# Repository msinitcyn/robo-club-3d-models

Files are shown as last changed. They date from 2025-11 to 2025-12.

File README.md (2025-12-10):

# 3D Models for Robotics Club



## Project: Robot Maze

### System Description

Building a maze for teaching robot navigation. The system consists of:

**Base:**
- Holes diameter: 5mm
- Grid spacing: 12.5mm
- Mounting points for wall connectors

**Walls:**
- Material: plywood (9mm) or cardboard (2mm)
- Shape: rectangles cut to size
- Insert into connector grooves
- For cardboard use models with `_flexible` suffix

**3D-printed connectors:**
- Height: 10mm
- Wall thickness: 2mm
- Groove width: 9mm (for plywood)
- Reach to mounting hole: 56.5mm (4.5 grid steps)

### Connector Types

1. **end_cap** - end cap (1 exit)
2. **straight_joint** - straight connector (2 opposite exits)
3. **corner_joint** - corner (2 exits at 90°)
4. **t_joint** - T-shaped (3 exits)
5. **cross_joint** - cross (4 exits)

Each type available in 4 variants:
- Base (no dowels, for plywood)
- `_dowel` (with dowels for base mounting)
- `_flexible` (flexible walls for cardboard, no dowels)
- `_dowel_flexible` (flexible walls + dowels)

**Total: 20 models**

### Project Structure

```
maze/
  scad/           # OpenSCAD source files
    common.scad   # Common modules and functions
    *_joint*.scad # Different connector types
  stl/            # Locally built STL (in .gitignore)
artifacts/        # CI/CD artifacts (automatic)
  current/        # Latest build from main branch
  v1.0/           # Version builds (for tags)
.github/
  workflows/      # GitHub Actions for auto-build
```

### Getting Ready STL Files

**Option 1: Download from GitHub (recommended)**
- Latest version: `artifacts/current/` in repository
- Stable version: [Releases](../../releases) → download attached STL files

**Option 2: Build locally**
```bash
./export_all_stl.sh
```
STL files will appear in `maze/stl/`

### Usage

1. Download STL files from `artifacts/current/` or [Releases](../../releases)
2. Print needed connectors
3. Prepare walls from plywood (9mm) or cardboard (2mm)
4. Assemble maze by inserting walls into connector grooves

### Development

1. Edit models: `maze/scad/*.scad` files in OpenSCAD
2. Test locally: `./export_all_stl.sh`
3. Commit changes → GitHub Actions automatically builds STL
4. For release: create tag `git tag v1.1 && git push origin v1.1`

### Parameters for Modification

In `common.scad` you can configure:

**Main dimensions:**
- `CENTER_SIZE = 9` - center square size
- `SLEEVE_REACH = 56.5` - distance to mounting hole
- `GROOVE_WIDTH = 9` - groove width (for plywood)
- `WALL_HEIGHT = 10` - wall height
- `WALL_THICKNESS = 2` - wall thickness
- `BASE_THICKNESS = 2` - base thickness

**Dowels:**
- `DOWEL_DIAMETER = 4.5` - dowel diameter
- `DOWEL_DEPTH = 3` - dowel depth

**Flexible walls (for cardboard):**
- `CARDBOARD_THICKNESS = 2` - cardboard thickness
- `FLEXIBLE_WALL_HEIGHT = 20` - flexible wall height (2x higher)
- `CURVE_POWER = 2` - curve power (2 = parabola)
- `TILT_ANGLE_EXTRA = 5` - additional tilt angle

### CI/CD Pipeline

On push to GitHub, STL build is triggered automatically:

**For regular commits (main branch):**
- All STL files are built
- Committed to `artifacts/current/`
- Available as GitHub Artifacts (90 days)

**For version tags (v1.0, v1.1, etc.):**
- All STL files are built
- GitHub Release is created with attached STL
- Available as GitHub Artifacts with version name

This allows to always have print-ready files without need for local OpenSCAD installation.

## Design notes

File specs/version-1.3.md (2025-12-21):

# Version 1.3 - LEGO Compatibility Improvements

Improvements to make parts better compatible with standard LEGO dimensions

## Changes Checklist

- [x] **1. Adjust LEGO base dimensions to match standard LEGO parts**
  - Files: All `lego_base_*.scad` files (including `_double` variants)
  - Changes in `maze/scad/lego.scad`:
    - Add new constants for LEGO-compatible dimensions
    - `LEGO_BASE_WIDTH` - width for single row of studs (≈8mm, to be tuned)
    - `LEGO_SLEEVE_LENGTH` - calculated to have exactly 7 studs total (center + sleeve) with equal margins from edges
    - Update modules to use new dimensions
  - Reason: Current parts too wide to attach to multi-row LEGO bricks

- [ ] **2. Create prototype with reduced base width**
  - File: `maze/scad/cross_joint_dowel_8_5_base_width.scad`
  - Change: `CENTER_SIZE = 8.5` (instead of 9.0)
  - Version tag: `v1.3.2-base.8.5.mm.proto`
  - Reason: Test if 8.5mm base fits better into 12.5mm grid holes (currently loose fit)
  - Note: Temporary experimental part - if successful, apply to all parts; if too tight, delete

## Implementation Notes

### For Change 1:
- Center should have 1 stud
- Each sleeve should have 3 studs
- Total: 1 + 3 + 3 = 7 studs
- Edge margins should be equal on both sides
- Formula: `LEGO_SLEEVE_LENGTH = 3 * LEGO_UNIT + margins`

### For Change 2:
- Single file to test reduced base size
- If approved, will become standard in future version
- If rejected, will be deleted

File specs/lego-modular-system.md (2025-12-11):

# Specification: LEGO-Compatible Modular System

## Concept

The system splits models into two layers connected via LEGO-compatible interface:

1. **Bottom Layer (Base)**
   - Optional dowels for mounting to grid base
   - LEGO studs on top for connecting upper layer

2. **Upper Layer (Wall Sleeve)**
   - LEGO holes underneath for connecting to base
   - Grooves on top for inserting plywood/cardboard walls

## Advantages

- **Modularity**: Print only the sleeves you need, attach to any base configuration
- **Flexibility**: Rigid walls (9mm plywood) or flexible walls (2mm cardboard)
- **Compatibility**: Can use real LEGO bricks for walls
- **Efficiency**: Empty center is normal - print 4 sleeves + 1 cross base for any configuration

## LEGO Standards

- Stud diameter: **4.8mm**
- Stud height: **1.8mm**
- Unit spacing: **8mm** (1 LEGO unit)
- Hole diameter: **5.0mm** (with clearance)
- Tube outer diameter: **6.5mm** (for spring grip)
- Tube inner diameter: **5.0mm**

## Dimensions

### Current Parameters
- `CENTER_SIZE = 9mm` (center square)
- `SLEEVE_LENGTH = 55mm` (actual sleeve length)
- `SLEEVE_REACH = 59.5mm` (calculated: from center to mounting hole)

### Stud Positions

**Formula:**
```
first_stud = LEGO_UNIT - (CENTER_SIZE/2 % LEGO_UNIT) = 8 - 4.5 = 3.5mm
```

**Center part:**
- 1 stud at center: **(0, 0)**

**Sleeve (local coordinates):**
- Sleeve starts at global coordinate **4.5mm** (edge of center square)
- Studs at local positions: **3.5, 11.5, 19.5, 27.5, 35.5, 43.5mm**

**Global coordinates (after assembly):**
- Center: **0mm**
- Sleeve: **8, 16, 24, 32, 40, 48mm**

**Verification:** All positions are multiples of 8mm ✓

### Visualization (top view, one sleeve along X axis)

```
    Center (9×9mm)    |      Sleeve (55mm)
                      |
    ----[═]----       |   [═]  [═]  [═]  [═]  [═]  [═]
        0mm           |   8   16   24   32   40   48
                    4.5mm (sleeve start)
```

## Module Structure

### Bottom Layer (Bases)
**File prefix:** `lego_base_*`

- `lego_base_straight[_dowel].scad` - straight base (center + 2 opposite sleeves)
- `lego_base_corner[_dowel].scad` - corner base (center + 2 sleeves at 90°)
- `lego_base_t[_dowel].scad` - T-shaped base (center + 3 sleeves)
- `lego_base_cross[_dowel].scad` - cross base (center + 4 sleeves)

**Variants:**
- Base (no dowels)
- `_dowel` (with dowels for grid mounting)

**Total:** 8 models

### Upper Layer (Wall Sleeves)
**File prefix:** `lego_wall_sleeve_*`

**Simple holes variant (for testing):**
- `lego_wall_sleeve.scad` - rigid walls (9mm plywood)
- `lego_wall_sleeve_flexible.scad` - flexible walls (2mm cardboard)

**Spring tubes variant (recommended):**
- `lego_wall_sleeve_tubes.scad` - rigid walls + inner tubes
- `lego_wall_sleeve_flexible_tubes.scad` - flexible walls + inner tubes

**Total:** 4 models

## Implementation Status

### ✅ Completed

1. **Code Architecture**
   - `common.scad` - base functionality for all models
   - `lego.scad` - LEGO-specific constants and modules (includes common.scad)
   - Constants refactored: SLEEVE_LENGTH is primary, SLEEVE_REACH is calculated

2. **Base Models (8 files)**
   - All 4 base configurations implemented
   - With/without dowel variants
   - LEGO studs positioned on 8mm grid
   - Z-offset parameterized for wall modules

3. **Wall Sleeve Models (4 files)**
   - Simple holes variant (5mm diameter holes)
   - Spring tubes variant (6.5mm outer, 5mm inner tubes)
   - Rigid and flexible wall variants for both
   - Base height = LEGO_STUD_HEIGHT (1.8mm)
   - Walls start at correct Z position

4. **LEGO Standards Compliance**
   - Stud positioning algorithm with boundary checks
   - Proper tube structure for spring grip
   - Holes penetrate full base thickness
   - Compatible with real LEGO bricks

### 🧪 Testing Required

- [ ] Print and test simple holes variant
- [ ] Print and test spring tubes variant
- [ ] Verify LEGO brick compatibility
- [ ] Test assembly/disassembly ease
- [ ] Check structural integrity

### 📋 Documentation

- [ ] Update main README with modular system description
- [ ] Add assembly instructions
- [ ] Document which variant to use when

## File Organization

```
maze/
  scad/
    common.scad           # Base functionality
    lego.scad             # LEGO-specific code

    # Base models (8 files)
    lego_base_straight.scad
    lego_base_straight_dowel.scad
    lego_base_corner.scad
    lego_base_corner_dowel.scad
    lego_base_t.scad
    lego_base_t_dowel.scad
    lego_base_cross.scad
    lego_base_cross_dowel.scad

    # Wall sleeve models (4 files)
    lego_wall_sleeve.scad                  # Simple holes, rigid
    lego_wall_sleeve_flexible.scad         # Simple holes, flexible
    lego_wall_sleeve_tubes.scad            # Spring tubes, rigid
    lego_wall_sleeve_flexible_tubes.scad   # Spring tubes, flexible

    # Legacy models (preserved)
    *_joint*.scad         # Original monolithic models
    end_cap*.scad
```

## Usage Example

1. Print `lego_base_cross.scad` → base with LEGO studs in cross pattern
2. Print 4× `lego_wall_sleeve_tubes.scad` → sleeves with rigid walls
3. Insert sleeves onto base via LEGO connection
4. Insert plywood walls (9mm) into grooves
5. Reconfigure anytime by swapping sleeves

## Technical Notes

### Boundary Checks
Studs are only placed if:
- First stud: `position >= LEGO_STUD_DIAMETER/2` from sleeve start
- Last stud: `position <= SLEEVE_LENGTH - LEGO_STUD_DIAMETER/2` from sleeve end

### Spring Tube Mechanism
- Tube height: 1.6mm (0.2mm below base surface)
- Stud (4.8mm) enters hole (5.0mm) inside tube
- Tube wall (0.75mm) deforms elastically
- Creates secure friction fit

### Z-Offset Parameter
All wall-drawing modules accept `z_offset` parameter:
- Legacy models: default `BASE_THICKNESS = 2mm`
- LEGO models: pass `LEGO_STUD_HEIGHT = 1.8mm`
- Allows mixing LEGO and non-LEGO components

## Legacy Compatibility

Original monolithic joint models are preserved:
- `straight_joint*.scad`
- `corner_joint*.scad`
- `t_joint*.scad`
- `cross_joint*.scad`
- `end_cap*.scad`

These continue to work with existing maze setups.

## Next Steps

1. Print test samples of both hole variants
2. Measure fit quality with real LEGO bricks
3. Adjust tolerances if needed (LEGO_HOLE_DIAMETER, LEGO_TUBE_OUTER_DIAMETER)
4. Update CI/CD to build new models
5. Create release with both variants

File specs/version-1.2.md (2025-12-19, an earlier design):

# Version 1.2 - Print Test Improvements

Based on print testing feedback, the following improvements are planned for version 1.2

## Changes Checklist

- [x] **1. Increase LEGO stud diameter**
  - File: `maze/scad/lego.scad`
  - Change: `LEGO_STUD_DIAMETER` from 4.8mm to 5.0mm
  - Reason: Current studs don't hold parts or authentic LEGO bricks securely

- [x] **2. Move version stamp to top surface and increase size**
  - File: `maze/scad/version.scad`
  - Changes:
    - Move version engraving from bottom (z=0) to top surfaces
    - Increase font size from 1.0mm to 2.0mm
  - Reason: Bottom surface has support material and version is not visible

- [x] **3. Fix LEGO niche design**
  - File: `maze/scad/lego.scad`
  - Changes:
    - Reduce `LEGO_NICHE_WIDTH` from 5.0mm to 4.8mm
    - Replace cylindrical supports between studs with perpendicular walls
  - Reason: Cylinders break when removing support material; niche too wide (LEGO bricks are loose)

- [x] **4. Increase dowel depth**
  - File: `maze/scad/common.scad`
  - Change: `DOWEL_DEPTH` from 3.0mm to 3.5mm
  - Reason: Dowels too short for secure mounting to base

- [x] **5. Create double-sided LEGO base series**
  - New files: 8 new .scad files
  - Feature: LEGO bases with studs on both top and bottom surfaces
  - Models:
    - lego_base_straight_double.scad
    - lego_base_straight_double_dowel.scad
    - lego_base_corner_double.scad
    - lego_base_corner_double_dowel.scad
    - lego_base_t_double.scad
    - lego_base_t_double_dowel.scad
    - lego_base_cross_double.scad
    - lego_base_cross_double_dowel.scad
  - Reason: Allow building maze structures in both directions

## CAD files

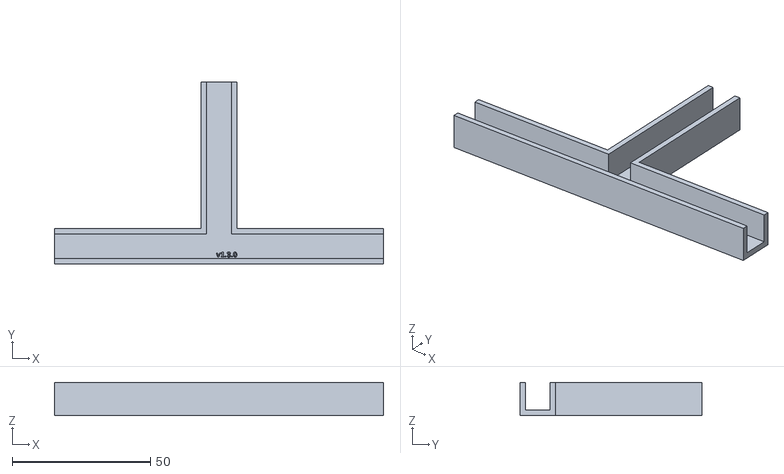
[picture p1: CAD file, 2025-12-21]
artifacts/current/t_joint.stl
119.0 x 66.0 x 12.0

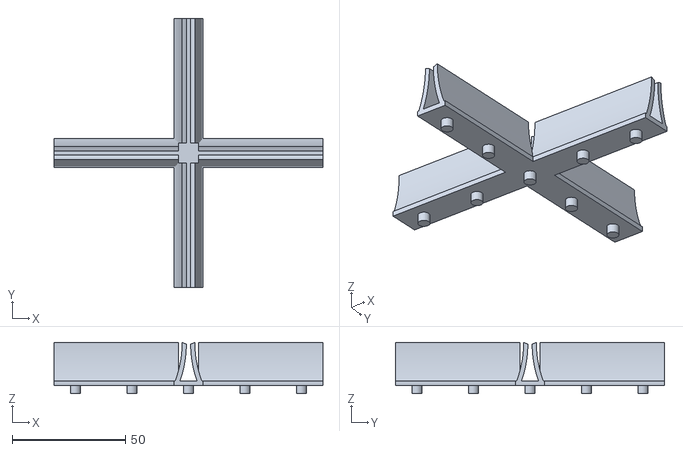
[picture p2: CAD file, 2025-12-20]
artifacts/v1.2/cross_joint_dowel_flexible.stl
119.0 x 119.0 x 22.6

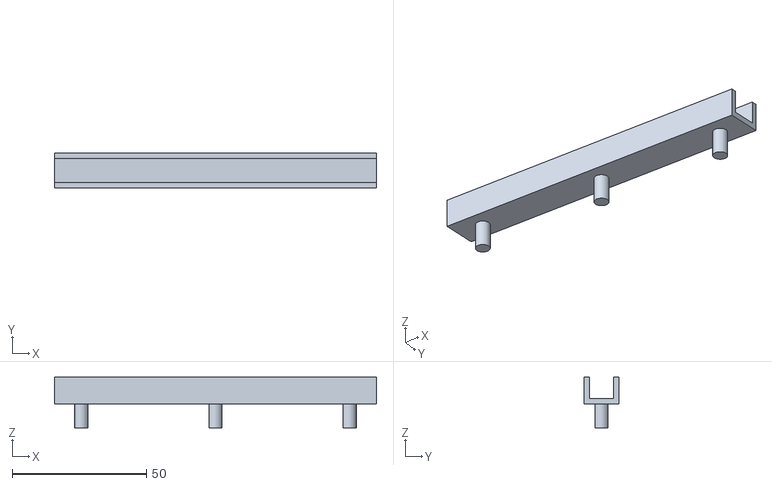
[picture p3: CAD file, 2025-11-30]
stl/straight_joint_dowel_long.stl
120.0 x 13.0 x 19.0

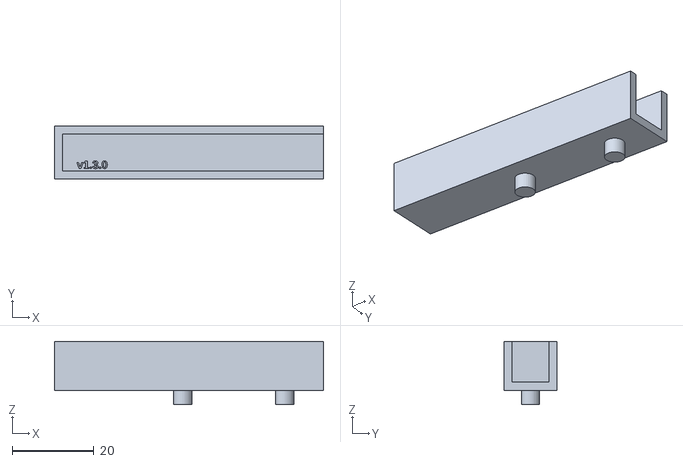
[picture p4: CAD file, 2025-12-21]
artifacts/current/end_cap_dowel.stl
66.0 x 13.0 x 15.5

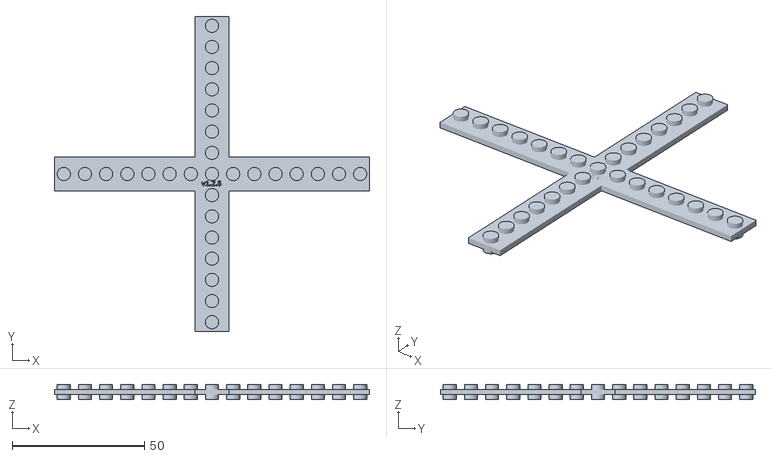
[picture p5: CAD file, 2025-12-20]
artifacts/v1.2/lego_base_cross_double.stl
119.0 x 119.0 x 5.60

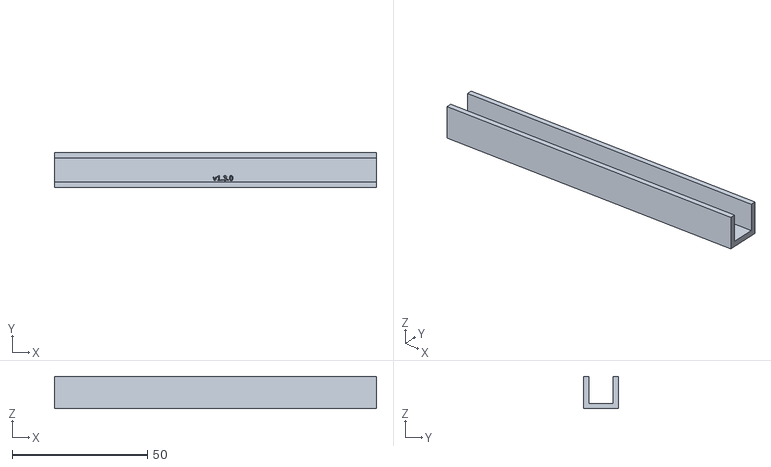
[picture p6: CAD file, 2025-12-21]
artifacts/current/straight_joint.stl
119.0 x 13.0 x 12.0

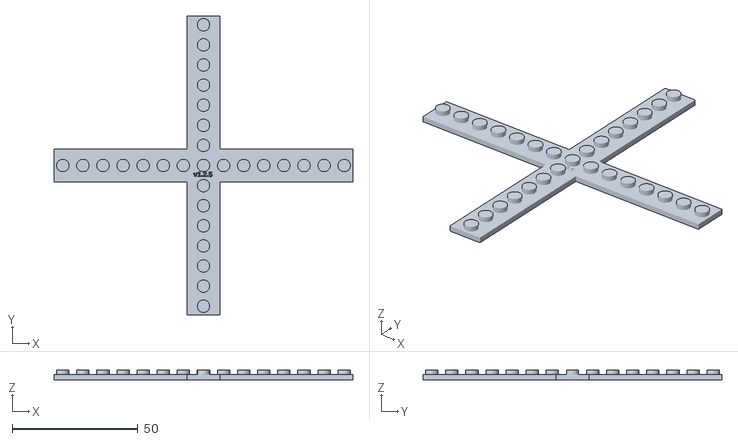
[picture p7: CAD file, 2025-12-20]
artifacts/v1.2/lego_base_cross.stl
119.0 x 119.0 x 3.80

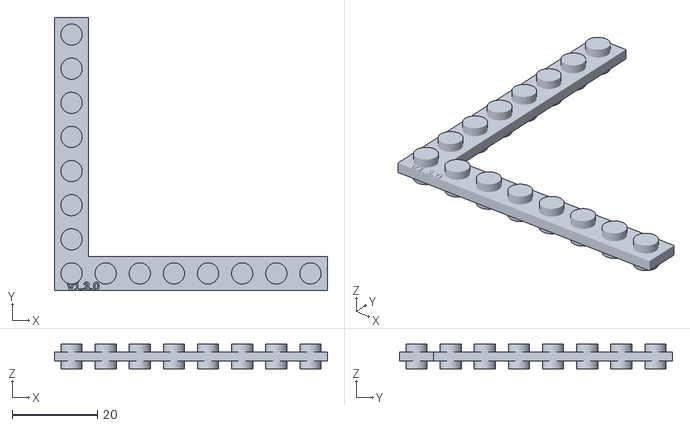
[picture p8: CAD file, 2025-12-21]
artifacts/current/lego_base_corner_double.stl
64.0 x 64.0 x 5.80

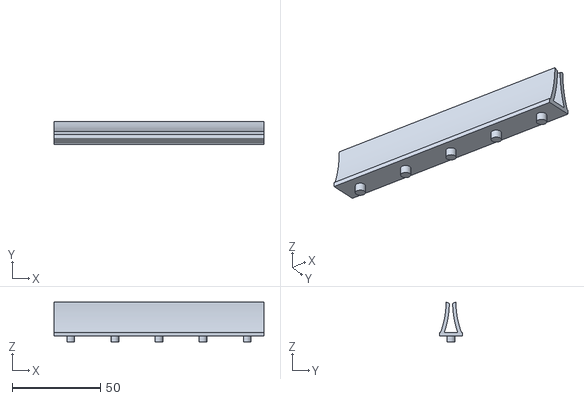
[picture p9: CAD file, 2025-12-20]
artifacts/v1.2/straight_joint_dowel_flexible.stl
119.0 x 13.0 x 22.6

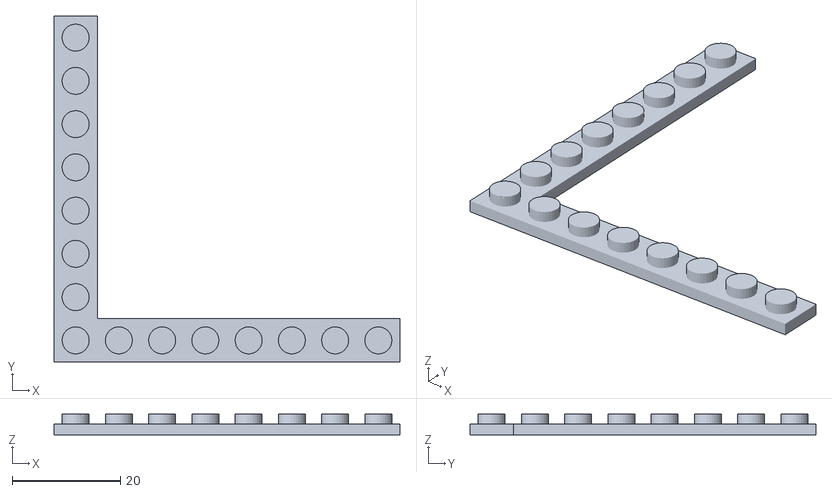
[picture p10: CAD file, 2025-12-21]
artifacts/current/lego_base_corner.stl
64.0 x 64.0 x 3.80

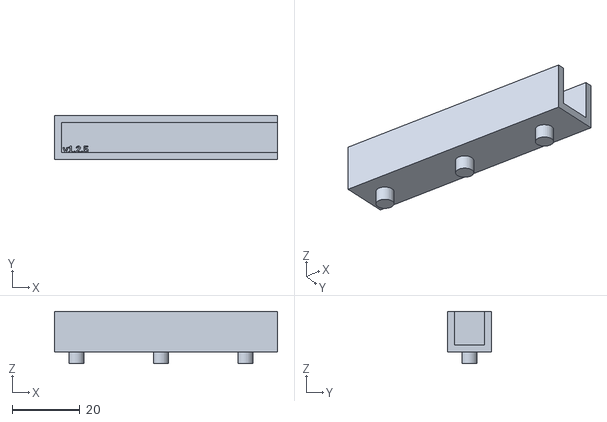
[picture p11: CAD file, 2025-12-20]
artifacts/v1.2/end_cap_dowel.stl
66.0 x 13.0 x 15.5

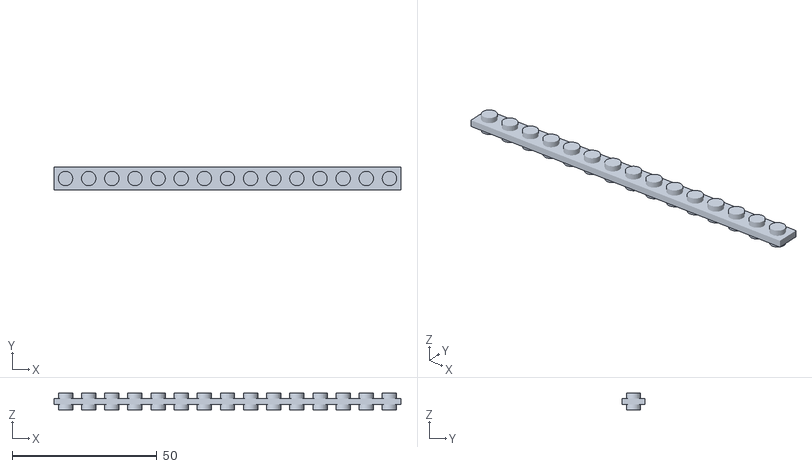
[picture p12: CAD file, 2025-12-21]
artifacts/current/lego_base_straight_double.stl
120.0 x 8.00 x 5.80

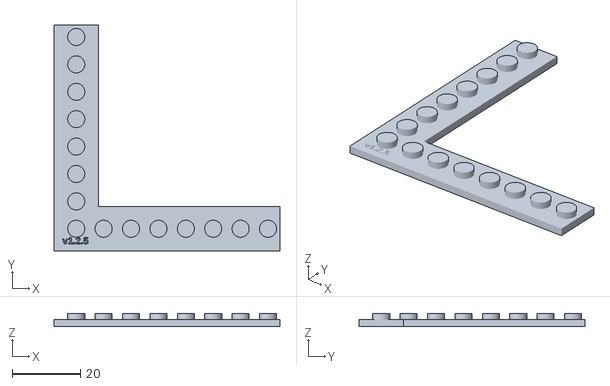
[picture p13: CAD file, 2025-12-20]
artifacts/v1.2/lego_base_corner.stl
66.0 x 66.0 x 3.80

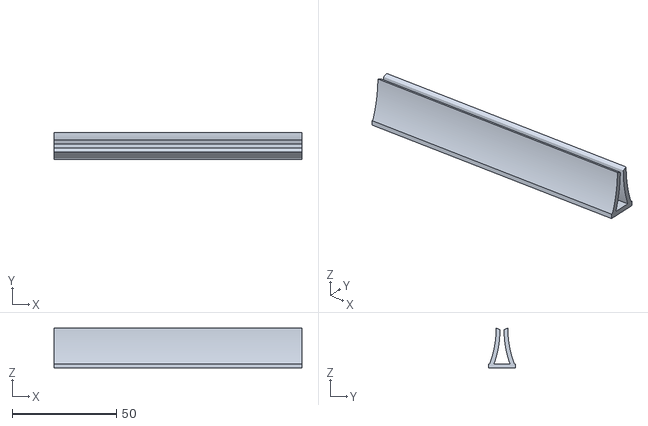
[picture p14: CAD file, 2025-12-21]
artifacts/current/straight_joint_flexible.stl
119.0 x 13.0 x 19.1

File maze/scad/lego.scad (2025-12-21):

include <common.scad>

LEGO_STUD_DIAMETER = 5.0;
LEGO_STUD_HEIGHT = 1.8;
LEGO_UNIT = 8;
LEGO_HOLE_DIAMETER = 5.0;

LEGO_BASE_WIDTH = 8.0;
LEGO_BASE_CENTER_SIZE = LEGO_UNIT;
LEGO_SLEEVE_STUDS = 7;
LEGO_SLEEVE_LENGTH = LEGO_SLEEVE_STUDS * LEGO_UNIT;
LEGO_TOTAL_WIDTH = LEGO_BASE_WIDTH;

module draw_lego_stud() {
    cylinder(h=LEGO_STUD_HEIGHT, d=LEGO_STUD_DIAMETER, $fn=30);
}

module draw_lego_hole() {
    cylinder(h=LEGO_STUD_HEIGHT + 0.1, d=LEGO_HOLE_DIAMETER, $fn=30);
}

module draw_lego_niche() {
    translate([-LEGO_HOLE_DIAMETER/2, -LEGO_HOLE_DIAMETER/2, 0])
        cube([LEGO_HOLE_DIAMETER, LEGO_HOLE_DIAMETER, LEGO_STUD_HEIGHT+0.1]);
}

module place_center_lego_stud() {
    translate([0, 0, BASE_THICKNESS])
        draw_lego_stud();
}

module place_sleeve_lego_studs(length, base_width = LEGO_BASE_CENTER_SIZE) {
    offset = base_width / 2;
    first_pos = LEGO_UNIT - offset;

    for (i = [0:20]) {
        pos = first_pos + i * LEGO_UNIT;
        if (pos + LEGO_STUD_DIAMETER/2 <= length) {
            translate([pos, 0, BASE_THICKNESS])
                draw_lego_stud();
        }
    }
}

module place_sleeve_lego_holes(length, base_width = LEGO_BASE_CENTER_SIZE) {
    offset = base_width / 2;
    first_pos = LEGO_UNIT - offset;

    for (i = [0:20]) {
        pos = first_pos + i * LEGO_UNIT;
        if (pos + LEGO_HOLE_DIAMETER/2 <= length) {
            translate([pos, 0, -0.05])
                draw_lego_hole();
        }
    }
}

module place_sleeve_lego_niche(length, base_width = LEGO_BASE_CENTER_SIZE) {
    offset = base_width / 2;
    first_pos = LEGO_UNIT - offset;

    for (i = [0:20]) {
        pos = first_pos + i * LEGO_UNIT;
        if (pos + LEGO_HOLE_DIAMETER/2 <= length) {
            translate([pos, 0, -0.05])
                draw_lego_niche();
        }
    }
}

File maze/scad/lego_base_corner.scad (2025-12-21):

include <lego.scad>
use <version.scad>

difference() {
    union() {
        place_center_base(LEGO_TOTAL_WIDTH);
        place_center_lego_stud();

        orient_sleeve(0, LEGO_BASE_CENTER_SIZE) {
            union() {
                place_sleeve_base(LEGO_SLEEVE_LENGTH, LEGO_TOTAL_WIDTH);
                place_sleeve_lego_studs(LEGO_SLEEVE_LENGTH);
            }
        }

        orient_sleeve(1, LEGO_BASE_CENTER_SIZE) {
            union() {
                place_sleeve_base(LEGO_SLEEVE_LENGTH, LEGO_TOTAL_WIDTH);
                place_sleeve_lego_studs(LEGO_SLEEVE_LENGTH);
            }
        }
    }

    print_version(top_z=3.8);
}

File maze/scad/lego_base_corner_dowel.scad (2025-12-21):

include <lego.scad>
use <version.scad>

difference() {
    union() {
        place_center_base(LEGO_TOTAL_WIDTH);
        place_center_lego_stud();
        place_center_dowel();

        orient_sleeve(0, LEGO_BASE_CENTER_SIZE) {
            union() {
                place_sleeve_base(LEGO_SLEEVE_LENGTH, LEGO_TOTAL_WIDTH);
                place_sleeve_lego_studs(LEGO_SLEEVE_LENGTH);
                place_sleeve_dowels(LEGO_SLEEVE_LENGTH, LEGO_TOTAL_WIDTH);
            }
        }

        orient_sleeve(1, LEGO_BASE_CENTER_SIZE) {
            union() {
                place_sleeve_base(LEGO_SLEEVE_LENGTH, LEGO_TOTAL_WIDTH);
                place_sleeve_lego_studs(LEGO_SLEEVE_LENGTH);
                place_sleeve_dowels(LEGO_SLEEVE_LENGTH, LEGO_TOTAL_WIDTH);
            }
        }
    }

    print_version(top_z=3.8);
}

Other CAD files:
artifacts/v1.2/lego_base_t.stl
artifacts/current/lego_base_t.stl
artifacts/v1.2/corner_joint_dowel_flexible.stl
artifacts/current/corner_joint_dowel_flexible.stl
maze/scad/lego_base_corner_double.scad
artifacts/current/corner_joint.stl
artifacts/current/corner_joint_dowel.stl
artifacts/current/corner_joint_flexible.stl
artifacts/current/cross_joint.stl
artifacts/current/cross_joint_dowel.stl
artifacts/current/cross_joint_dowel_flexible.stl
artifacts/current/cross_joint_flexible.stl
artifacts/current/end_cap.stl
artifacts/current/end_cap_dowel_flexible.stl
artifacts/current/end_cap_flexible.stl
artifacts/current/lego_base_corner_dowel.stl
artifacts/current/lego_base_cross.stl
artifacts/current/lego_base_cross_double.stl
artifacts/current/lego_base_cross_dowel.stl
artifacts/current/lego_base_straight.stl
artifacts/current/lego_base_straight_dowel.stl
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

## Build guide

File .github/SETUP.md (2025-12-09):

# GitHub Actions Setup Instructions

## Первоначальная настройка

### 1. Обновить badge в README.md

Замените в `README.md` строку:
```markdown
![Build STL Files](https://github.com/YOUR_USERNAME/YOUR_REPO/actions/workflows/build-stl.yml/badge.svg)
```

На актуальные значения вашего репозитория:
```markdown
![Build STL Files](https://github.com/USERNAME/3d-models/actions/workflows/build-stl.yml/badge.svg)
```

### 2. Настройка permissions для GitHub Actions

Чтобы workflow мог коммитить artifacts обратно в репозиторий:

1. Перейдите в: **Settings** → **Actions** → **General**
2. Найдите раздел **Workflow permissions**
3. Выберите **Read and write permissions**
4. Сохраните изменения

### 3. Первый запуск

После настройки:

```bash
# Добавить новые файлы
git add .github/ .gitignore README.md

# Создать коммит
git commit -m "Add CI/CD pipeline for automatic STL generation"

# Запушить в main (запустится автосборка)
git push origin main
```

Workflow запустится автоматически и:
1. Соберёт все STL файлы
2. Закоммитит их в `artifacts/current/`
3. Создаст GitHub Artifacts на 90 дней

## Проверка работы

### Посмотреть статус сборки

1. Перейдите на вкладку **Actions** в репозитории
2. Найдите последний запуск "Build STL Files"
3. Проверьте, что все шаги зелёные ✓

### Скачать готовые STL

**Из Artifacts:**
1. Actions → последний успешный запуск
2. Внизу страницы: **Artifacts** → `stl-files-current`
3. Скачать zip архив

**Из репозитория:**
1. Перейти в папку `artifacts/current/`
2. Скачать нужные `.stl` файлы

## Создание релиза

Для создания стабильной версии с GitHub Release:

```bash
# Создать тег
git tag -a v1.1 -m "Version 1.1: Description of changes"

# Запушить тег
git push origin v1.1
```

Workflow автоматически:
1. Соберёт все STL
2. Создаст GitHub Release с версией v1.1
3. Прикрепит все STL файлы к релизу
4. Сгенерирует release notes

## Troubleshooting

### Workflow не запускается

- Проверьте, что workflow файл в правильном месте: `.github/workflows/build-stl.yml`
- Проверьте, что в Settings → Actions включены workflows

### Ошибка при коммите artifacts

- Проверьте **Workflow permissions** (должно быть Read and write)
- Проверьте, что ветка `main` не защищена от force push

### OpenSCAD ошибки при сборке

- Проверьте синтаксис в `.scad` файлах локально
- Убедитесь, что все файлы используют `use <common.scad>` а не `include`
- Проверьте логи в Actions для деталей ошибки

## Структура workflow

Workflow состоит из следующих шагов:

1. **Checkout** - клонирование репозитория
2. **Install OpenSCAD** - установка OpenSCAD и Xvfb (для headless режима)
3. **Build STL** - запуск `export_all_stl.sh`
4. **Determine path** - определение пути (current или версия)
5. **Upload artifacts** - загрузка в GitHub Artifacts
6. **Create Release** - (только для тегов) создание релиза
7. **Commit artifacts** - (только для main) коммит в artifacts/current

## Кастомизация

### Изменить retention период artifacts

В `.github/workflows/build-stl.yml`:
```yaml
retention-days: 90  # Измените на нужное значение (1-90)
```

### Отключить автокоммит в artifacts/

Удалите или закомментируйте шаг "Commit artifacts to repository".
Артефакты всё равно будут доступны как GitHub Artifacts.

### Добавить уведомления

Добавьте в конец workflow:
```yaml
- name: Notify on failure
  if: failure()
  uses: actions/github-script@v6
  with:
    script: |
      github.rest.issues.create({
        owner: context.repo.owner,
        repo: context.repo.repo,
        title: 'STL Build Failed',
        body: 'Automatic STL generation failed. Check the workflow logs.'
      })
```

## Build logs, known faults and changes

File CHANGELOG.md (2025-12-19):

# Changelog

All notable changes to this project will be documented in this file.

The format is based on [Keep a Changelog](https://keepachangelog.com/en/1.0.0/).

## [Unreleased]

## [1.1.1]

### Changed
- Initial LEGO support implementation
- Added version stamping on all parts

## [1.0.0] - Initial release

### Added
- Maze connector system (end_cap, straight_joint, corner_joint, t_joint, cross_joint)
- Wall sleeves with dowel mounting variants
- Flexible wall variants for cardboard (2mm thickness)
- Parametric design with configurable dimensions

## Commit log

2025-11-30 initial models
    [corner_joint.scad, corner_joint.stl, corner_joint_dowel.scad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]
2025-11-30 update stl
    [corner_joint_dowel_long.stl, cross_joint_dowel.stl, cross_joint_dowel_long.stl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]
2025-11-30 fixed models
    [common.scad, corner_joint.scad, corner_joint_dowel.scad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]
2025-12-02 added more models. hopefully more robust
    [corner_joint_short_dowel.scad, corner_joint_short_dowel.stl, cross_joint_dowel.stl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]
2025-12-07 added flexible joints
    [common.scad, corner_joint_dowel_flexible.scad, corner_joint_flexible.scad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]
2025-12-07 changed dowel diameter
    [common.scad]
2025-12-07 added stl
    [corner_joint.stl, corner_joint_dowel.stl, corner_joint_dowel_flexible.stl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]
2025-12-09 added github workflow to automate stl creation
2025-12-09 Update STL artifacts (current)
    [corner_joint.stl, corner_joint_dowel.stl, corner_joint_dowel_flexible.stl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]
2025-12-09 cleanup. version 1.0
    [corner_joint.stl, corner_joint_dowel.stl, corner_joint_dowel_flexible.stl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]
2025-12-09 fix stl workflow
2025-12-09 removed comments
    [common.scad, corner_joint.scad, corner_joint_dowel.scad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]
2025-12-09 Add STL artifacts for v1.0
    [corner_joint.stl, corner_joint_dowel.stl, corner_joint_dowel_flexible.stl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]
2025-12-11 added lego compatible base
    [common.scad, lego_base_corner.scad, lego_base_corner_dowel.scad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]
2025-12-11 added lego sleeves. refactoring
    [common.scad, lego.scad, lego_base_corner.scad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]
2025-12-16 added lego mimicking models
    [common.scad, lego.scad, lego_base_cross.scad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]
2025-12-16 removed lego tube models
    [lego.scad, lego_wall_sleeve_flexible_tubes.scad, lego_wall_sleeve_tubes.scad]
2025-12-16 added versioning
    [corner_joint.scad, corner_joint_dowel.scad, corner_joint_dowel_flexible.scad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]
2025-12-16 fixed lego niche size
    [lego.scad, version.scad]
2025-12-16 clean up stl before generation
2025-12-19 increased lego stud
    [lego.scad, version.scad]
2025-12-19 moved version to top surface
    [version.scad]
2025-12-19 fixed lego niche sleeves
    [lego.scad, version.scad]
2025-12-19 increased dowels height
    [common.scad, version.scad]
2025-12-19 introduced double sided lego compatible details
    [lego.scad, lego_base_corner_double.scad, lego_base_cross_double.scad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]
2025-12-20 Add STL artifacts for v1.2
    [corner_joint.stl, corner_joint_dowel.stl, corner_joint_dowel_flexible.stl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]
2025-12-21 refactored model building approach. ajusted lego_double sizes
    [common.scad, corner_joint.scad, corner_joint_dowel.scad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]
